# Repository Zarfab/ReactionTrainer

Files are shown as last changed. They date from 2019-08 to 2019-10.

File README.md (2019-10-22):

# ReactionTrainer
These modules are developed with the aim of creating exercises to improve athletes' reflexes.

## How to use

## Make your own

### Bill of material
(For each module)

|Part|Reference|cost|Other information|
|----|----|----|----|
|Micro-controller|ESP32 D1 Mini|3,80€|
|Distance sensor|VL6180X|2.40€|[datasheet](https://www.st.com/resource/en/datasheet/vl6180x.pdf)
|RGB LED ring|WS2812B ring|3.30€|12 LED, outer diameter 52mm|
|Buzzer|12085 16R|0.20€|Often sold in packs of 5 or 10|
|Battery|18650|3.00€|
|Battery holder|For 1x 18650 cell|0.55€|
|On / Off switch|TS-13|1.00€|
|Case|3D printed||

Total cost for a single module is around 15€ without the case.

### Software requirement
- [Arduino IDE 1.8.6](https://www.arduino.cc/en/main/software) or newer with [Arduino Core for ESP32 installed](https://github.com/espressif/arduino-esp32/blob/master/docs/arduino-ide/boards_manager.md)
- [FastLED](https://github.com/FastLED/FastLED) (install latest from Arduino IDE Librairies Manager)
- [arduinoWebSockets](https://github.com/Links2004/arduinoWebSockets) (install latest - at least v 2.x.x - from Arduino IDE Librairies Manager)
- [arduinoJson](https://github.com/bblanchon/ArduinoJson) (install latest - at least v 6.x.x - from Arduino IDE Librairies Manager)
- [VL6180X (Polulu)](https://github.com/pololu/vl6180x-arduino) (install latest from Arduino IDE Librairies Manager)

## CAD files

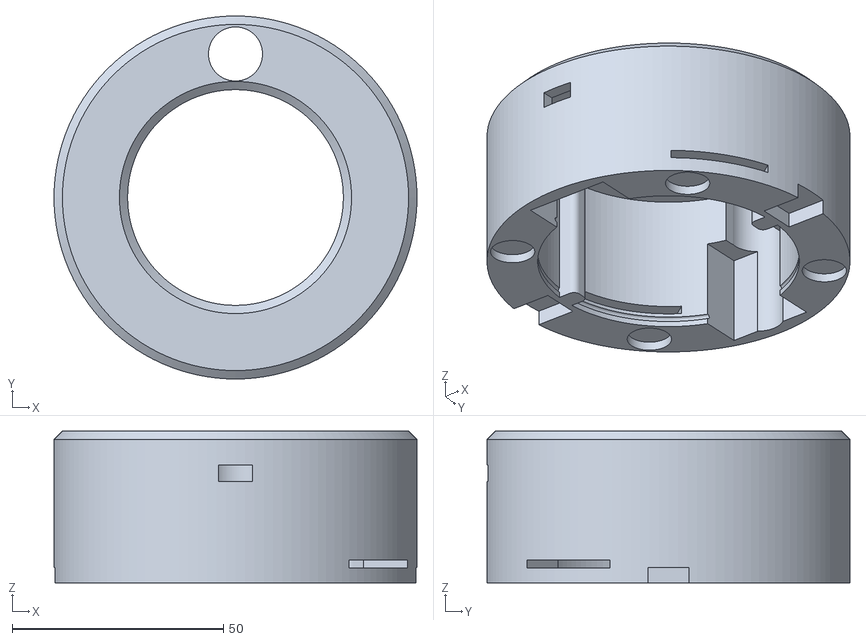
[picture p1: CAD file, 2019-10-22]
CAD/RoundBox.stl
86.0 x 86.0 x 36.0

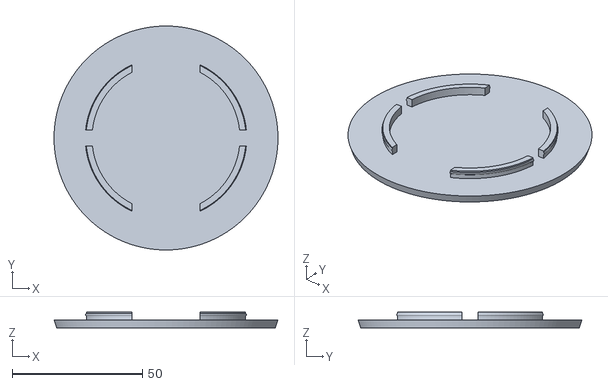
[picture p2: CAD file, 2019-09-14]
CAD/BottomPlate.stl
86.0 x 86.0 x 6.00

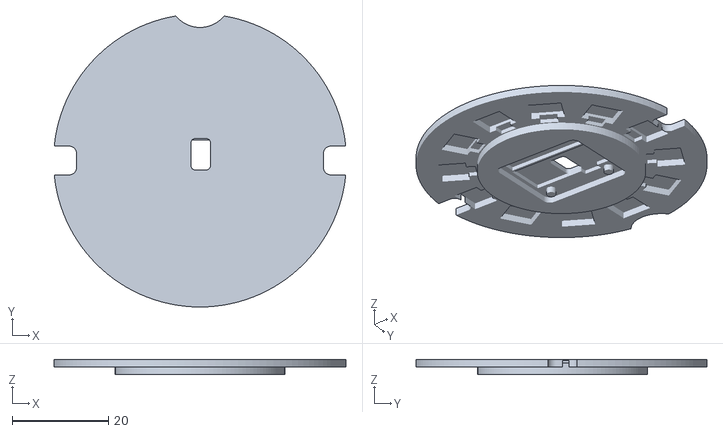
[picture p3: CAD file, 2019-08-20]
CAD/TopPlate.stl
60.5 x 60.4 x 3.20

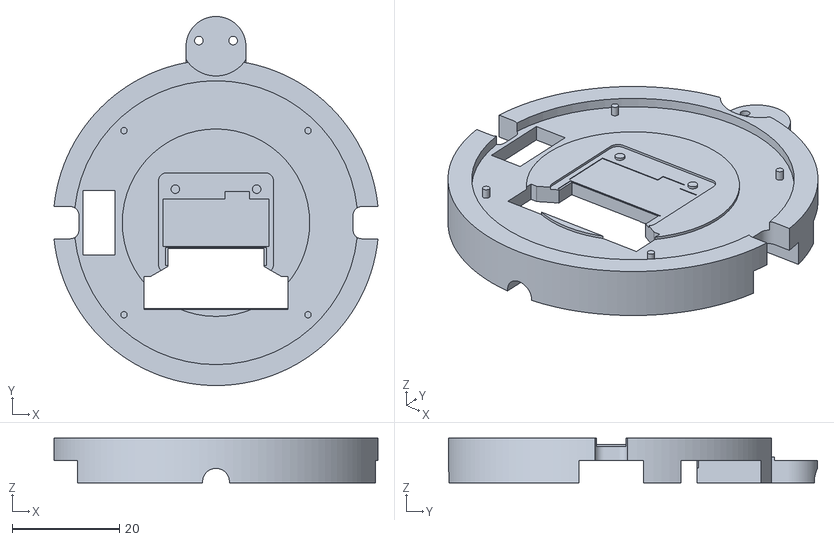
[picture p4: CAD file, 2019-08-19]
CAD/InnerPlate.stl
60.5 x 68.9 x 8.35

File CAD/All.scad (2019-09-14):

use<components.scad>
use<RoundBox.scad>
use<TopPlate.scad>
use<InnerPlate.scad>
use<BottomPlate.scad>


difference() {
    union() {
        roundBox();
        //translate([0, 0, 30.4]) components();
        //#color([0.2, 1, 0.4]) translate([0, 0, 0.6]) batteryHolder();
        //#translate([0, 0, 32.4]) TopPlate();
        //color([0.9, 0.9, 0.9]) translate([0, 0, 27.8]) InnerPlate();
        translate([0, 0, -3]) BottomPlate();
    }
    rotate(60) translate([0, -50, -5]) cube([100, 100, 60]);
}

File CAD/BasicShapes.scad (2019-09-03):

module roundedRect(size, radius)
{
    x = size[0]-radius;
    y = size[1]-radius;
    z = size[2];

    linear_extrude(height=z)
    hull()
    {
        // place 4 circles in the corners, with the given radius
        translate([(-x/2)+(radius/2), (-y/2)+(radius/2), 0])
        circle(r=radius);

        translate([(x/2)-(radius/2), (-y/2)+(radius/2), 0])
        circle(r=radius);

        translate([(-x/2)+(radius/2), (y/2)-(radius/2), 0])
        circle(r=radius);

        translate([(x/2)-(radius/2), (y/2)-(radius/2), 0])
        circle(r=radius);
    }
}



module tore(mainRadius, circleRadius, fn1 = $fn, fn2 = $fn)
{
    rotate_extrude(convexity = 10, $fn = fn1)
    translate([mainRadius, 0, 0])
    circle(r = circleRadius, $fn = fn2);
}

tore(10, 2, fn1 = 120, fn2 = 12);

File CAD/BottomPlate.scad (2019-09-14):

use <BasicShapes.scad>

$fn = 120;

module BottomPlate() {
    difference() {
        union() {
            cylinder(d1=84, d2=86, h=3);
            //translate([0,0,2.9]) cylinder(d=86, h=3.1);
            translate([0,0,3]) difference() {
                union() {
                    space = 0.28;
                    cylinder(d=62 - 2 * space, h=3);
                    translate([0,0,2]) tore(mainRadius=31 - space - 0.2, circleRadius=0.5);
                }
                cylinder(d=56.8, h=3.1);
                translate([31-1.8, 0, 0]) roundedRect(size=[7.2, 6, 4.4], radius=1.6);
        translate([-31+1.8, 0, 0]) roundedRect(size=[7.2, 6, 4.4], radius=1.6);
                translate([0, 0, 3]) cube([26, 78, 6], center=true);
            }
        }
        //translate([0,0,2.9]) cylinder(d=84, h=3.2);
        /*for(i=[0:3]) {
            rotate([0, 0, 45 + i*90]) translate([0, 37, 0.1]) {
                translate([0, 0, -0.2]) cylinder(d=8.2, h=0.3);
                cylinder(d1=8.2, d2=4.4, h=2.4);
                cylinder(d=4.4, h=4.2);
            }
        }*/
    }
}

BottomPlate();

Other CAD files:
CAD/components.scad
CAD/InnerPlate.scad
CAD/RoundBox.scad
CAD/RoundedRect.scad
CAD/TopPlate.scad

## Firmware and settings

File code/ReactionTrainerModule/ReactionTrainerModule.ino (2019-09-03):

#include <WiFi.h>
#include <WebSocketsClient.h>
#include <ArduinoJson.h>
#include "RTModule.h"

#define AP_SSID_PREFIX "REACTION_TRAINER_"
#define AP_PASSWORD "PainIsComing"

#define BOOT_COLOR          CRGB::Gray
#define WIFI_NOT_FOUND      CRGB::Orange
#define WIFI_CONNECTING     CRGB::Yellow
#define WIFI_NOT_CONNECTED  CRGB::Red
#define WIFI_CONNECTED      CRGB::Chartreuse
#define WS_CONNECTED        CRGB::Cyan
#define WS_DISCONNECTED     CRGB::Magenta

#define JSON_OVER_SERIAL false // used at true for debug


DynamicJsonDocument doc(1024);
WebSocketsClient webSocket;
RTModule reactionTrainer;

    
/**************************************************************************/
/*  Arduino main funtions                                                 */
/**************************************************************************/
void setup()
{
  Serial.begin(115200);

  reactionTrainer.init();

  ///// SCAN WIFI NETWORKS /////
  // Set WiFi to station mode and disconnect from an AP if it was previously connected
  if(!JSON_OVER_SERIAL) {
    WiFi.mode(WIFI_STA);
    WiFi.disconnect();
    fill_solid(reactionTrainer.leds, NB_LED, BOOT_COLOR);
    FastLED.show();
    delay(100);
    int n = WiFi.scanNetworks();
    Serial.println("scan done");
    if (n == 0) 
    {
        Serial.println("no network found");
        fill_solid(reactionTrainer.leds, NB_LED, WIFI_NOT_FOUND);
        FastLED.show();
        delay(5000);
        ESP.restart();
    } 
    
    String ssid = "";
    for (int i = 0; i < n; ++i) 
    {
      String currentSsid = WiFi.SSID(i);
      if(currentSsid.indexOf(AP_SSID_PREFIX) == 0) 
      {
        ssid = currentSsid;
        Serial.printf("Will try to connect to %s, signal force is %i dB\n", WiFi.SSID(i), WiFi.RSSI(i));
        fill_solid(reactionTrainer.leds, NB_LED, WIFI_CONNECTING);
        FastLED.show();
        break;
      }
      delay(10);
    }
    if(ssid == "") {
      Serial.printf("no network with %s as prefix\n", AP_SSID_PREFIX);
      fill_solid(reactionTrainer.leds, NB_LED, WIFI_NOT_FOUND);
      FastLED.show();
      delay(5000);
      ESP.restart();
    }
    
    WiFi.begin(ssid.c_str(), AP_PASSWORD);
    int nbTries = 0;
    while(WiFi.status() != WL_CONNECTED) {
      delay(500);
      Serial.print(".");
      if(nbTries % 4 == 3) {
        WiFi.begin(ssid.c_str(), AP_PASSWORD);
      }
      if(nbTries >= 20) {
        Serial.println("impossible to connect to " + ssid + ", check if password is set correctly");
        fill_solid(reactionTrainer.leds, NB_LED, WIFI_NOT_CONNECTED);
        FastLED.show();
        delay(5000);
        ESP.restart();
      }
      nbTries++;
    }
  
    Serial.println();
    Serial.println("WiFi connected");
    Serial.print("SSID: ");
    Serial.println(WiFi.SSID());
    Serial.print("IP address: ");
    Serial.println(WiFi.localIP());
    fill_solid(reactionTrainer.leds, NB_LED, WIFI_CONNECTED);
    FastLED.show();
    delay(100);
  
    webSocket.begin("192.168.4.1", 8025, "/rt");
    webSocket.onEvent(webSocketEvent);
    webSocket.setReconnectInterval(5000);
  }
  else {
    fill_solid(reactionTrainer.leds, NB_LED, BOOT_COLOR);
    FastLED.show();
    delay(100);
  }
}



void loop()
{
  if(!JSON_OVER_SERIAL) webSocket.loop();
  else {
    if(Serial.available()) {
      DeserializationError err = deserializeJson(doc, Serial);
      if(err == DeserializationError::Ok)
        reactionTrainer.handleJson(doc.as<JsonObject>());
      else 
        Serial.printf("deserializeJson() failed with code %s\n", err.c_str());
    }
  }
  String answer = reactionTrainer.update();
  if(answer != "")
  {
    if(!JSON_OVER_SERIAL) webSocket.sendTXT(answer);
    else Serial.println(answer);
  }
  FastLED.show();
}



/**************************************************************************/
/*  WebSocket callbacks                                                   */
/**************************************************************************/
void webSocketEvent(WStype_t type, uint8_t * payload, size_t length)
{
    switch(type)
    {
        case WStype_DISCONNECTED:
          Serial.printf("[WSc] Disconnected!\n");
          fill_solid(reactionTrainer.leds, NB_LED, WS_DISCONNECTED);
          break;
        case WStype_CONNECTED:
          Serial.printf("[WSc] Connected to url: %s\n", payload);
          fill_solid(reactionTrainer.leds, NB_LED, WS_CONNECTED);
          break;
        case WStype_TEXT:
        {
          Serial.printf("[WSc] get text: %s\n", payload);
          DeserializationError err = deserializeJson(doc, payload);
          if(err == DeserializationError::Ok)
            reactionTrainer.handleJson(doc.as<JsonObject>());
          else 
            Serial.printf("deserializeJson() failed with code %s\n", err.c_str());
        }
        break;
      default:  
        break;
    }
}

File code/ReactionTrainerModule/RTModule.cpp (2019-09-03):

#include "RTModule.h"

RTModule::RTModule() :
  brightness(32), groupColor(0xff0000), presentSelf(false), shotT0(-1), buzzerOn(false)
{
  defaultShot.distanceThreshold = 200;
  defaultShot.timeout = 4000;
  defaultShot.order = SIMULTANEOUS;
  
  defaultShot.colorDuration = 1500;
  fill_solid(defaultShot.colorPalette, 16, CRGB::Blue);
  defaultShot.colorAnim = COLOR_ANIM_NONE;
  
  defaultShot.soundDuration = 0;
  defaultShot.soundFreq = -1;
}



void RTModule::init()
{
  ///// SETUP FASTLED AND DISPLAY BATTERY LEVEL /////
  FastLED.addLeds<WS2812B, LED_PIN, GRB>(leds, NB_LED).setCorrection( TypicalLEDStrip );
  FastLED.setBrightness(brightness);
  showBatteryLevel();
  FastLED.delay(1000);
  // setup VL6180X sensor
  Wire.begin();
  sensor.init();
  sensor.configureDefault();
  sensor.setTimeout(200);
  // setup buzzer
  ledcSetup(buzzerChannel, 440, 8);
  ledcAttachPin(BUZZER_PIN, buzzerChannel);
}



String RTModule::update()
{
  String str = "";
  if(presentSelf) {
    StaticJsonDocument<64> doc;
    doc["type"] = "RTModule";
    doc["version"] = RT_VERSION;
    char buf[64];
    serializeJson(doc, buf);
    str += buf;
    presentSelf = false;
    return str;
  }
  if(shotT0 >= 0) {
    int64_t reactTime = millis() - shotT0;
    // play sound
    if(!buzzerOn && shot.soundFreq > 20 && reactTime >= shot.soundT0) {
      ledcWriteTone(buzzerChannel, shot.soundFreq);
      buzzerOn = true;
    }
    // stop sound;
    if(buzzerOn && reactTime >= shot.soundTEnd) {
      ledcWriteTone(buzzerChannel, 0);
      buzzerOn = false;
      shot.soundFreq = -1; // prevent from playing again
    }
    // play color animation
    if(reactTime >= shot.colorT0 && reactTime < shot.colorTEnd) {
      int64_t animTime = reactTime - shot.colorT0;
      float animProgress = animTime / (float)(shot.colorDuration);
      int paletteIndex = round(255.0 * animProgress);
      CRGB currentColor = ColorFromPalette(shot.colorPalette, paletteIndex);
      switch(shot.colorAnim) {
        case COLOR_ANIM_NONE:
          fill_solid(leds, NB_LED, shot.colorPalette[0]);
          break;
        case COLOR_ANIM_STILL:
          fill_solid(leds, NB_LED, currentColor);
          break;
        case COLOR_ANIM_BLINK:
        {
          bool isBlack = animTime % 200 >= 100;
          fill_solid(leds, NB_LED, isBlack? CRGB::Black : currentColor);
        }
          break;
        case COLOR_ANIM_TIMER:
        {
          for(int i = 0; i < NB_LED; i++) {
            if(i <= floor(animProgress * NB_LED)) {
              leds[i] = currentColor;
            }
            else {
              leds[i] = CRGB::Black;
            }
          }
        }
          break;
        case COLOR_ANIM_STOPWATCH:
        {
          for(int i = 0; i < NB_LED; i++) {
            if(i <= floor((1.0 - animProgress) * NB_LED)) {
              leds[i] = currentColor;
            }
            else {
              leds[i] = CRGB::Black;
            }
          }
        }
          break;
        case COLOR_ANIM_LOADING:
        {
          fill_solid(leds, NB_LED, CRGB::Black);
          int firstLed = (NB_LED * animTime / 492) % NB_LED;
          for(int i = firstLed; i < firstLed + NB_LED / 2; i++) {
            leds[i % NB_LED] = currentColor;
          }
        }
          break;
        case COLOR_ANIM_WHEEL:
        {
          fill_solid(leds, NB_LED, CRGB::Black);
          int firstLed = (NB_LED * animTime / 2000) % 4;
          for(int i = firstLed; i < NB_LED; i += 4) {
              leds[i] = currentColor;
          }
          break;
        }
        default:
          break;
      }
    }
    else {
      fill_solid(leds, NB_LED, CRGB::Black);
    }
    
    // read sensor value
    uint16_t val = sensor.readRangeSingle();
    if (val <= shot.distanceThreshold || reactTime > shot.timeout) {
      StaticJsonDocument<64> doc;
      doc["result"] = val <= shot.distanceThreshold? 1 : 0;
      doc["reactionTime"] = reactTime;
      char buf[64];
      serializeJson(doc, buf);
      str += buf;
      shotT0 = -1;
      fill_solid(leds, NB_LED, CRGB::Black);
      ledcWriteTone(buzzerChannel, 0);
      buzzerOn = false; 
    }
  }
  return str;
}



void RTModule::handleJson(const JsonObject& doc)
{
  JsonVariant brightnessJson = doc["brightness"];
  JsonVariant groupColorJson = doc["groupColor"];
  if(!brightnessJson.isNull() && !groupColorJson.isNull()) {
    brightness = brightnessJson.as<uint8_t>();
    groupColor = groupColorJson.as<int>();
    presentSelf = strcmp(doc["answerExpected"], "true") == 0;
    FastLED.setBrightness(brightness);
    fill_solid(leds, NB_LED, groupColor);
    FastLED.show();
    FastLED.delay(1000);
    fill_solid(leds, NB_LED, CRGB::Black);
    FastLED.show();
  }
  else
  {
    // configure and measure reaction time
    shot.distanceThreshold = doc["distanceThreshold"] | defaultShot.distanceThreshold;
    shot.timeout = doc["timeout"] | defaultShot.timeout;
    shot.order = doc["order"].as<uint8_t>() | defaultShot.order;
  
    shot.colorDuration = doc["colorDuration"] | defaultShot.colorDuration;
    shot.colorAnim = doc["colorAnim"].as<uint8_t>() | defaultShot.colorAnim;
    JsonArray palette = doc["colorPalette"];
    if(palette.isNull())
    {
      CRGB colorBeg = doc["colorBegin"].as<int>();
      if(colorBeg) {
        CRGB colorEnd = doc["colorEnd"].as<int>();
        if(colorEnd) {
          fill_gradient_RGB(shot.colorPalette, 16, colorBeg, colorEnd);
        }
        else {
          fill_solid(shot.colorPalette, 16, colorBeg);
        }
      }
      else {
        shot.colorPalette =  defaultShot.colorPalette;
      }
    }
    else
    {
      fill_solid(shot.colorPalette, 16, CRGB::Black);
      int i = 0;
      for(JsonVariant v : palette) 
      {
        shot.colorPalette[i] = v.as<int>();
        i++;
        if(i == 16) break;
      }
    }
  
    shot.soundDuration = doc["soundDuration"] | defaultShot.soundDuration;
    shot.soundFreq = doc["soundFreq"] | defaultShot.soundFreq;

    switch(shot.order) {
      case COLOR_BEFORE:
        shot.colorT0 = 0;
        shot.colorTEnd = shot.colorDuration;
        shot.soundT0 = shot.colorDuration;
        shot.soundTEnd = shot.colorDuration + shot.soundDuration;
        break;
      case SOUND_BEFORE:
        shot.colorT0 = shot.soundDuration;
        shot.colorTEnd = shot.soundDuration + shot.colorDuration;
        shot.soundT0 = 0;
        shot.soundTEnd = shot.soundDuration;
        break;
      default:
        shot.colorT0 = 0;
        shot.colorTEnd = shot.colorDuration;
        shot.soundT0 = 0;
        shot.soundTEnd = shot.soundDuration;
        break;
    }
    shotT0 = millis();
  }
}
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

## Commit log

2019-08-18 First draw of CAD finished
    [BottomPlate.scad, BottomPlate.stl, InnerPlate.scad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]
2019-08-18 Correct led ring size
2019-08-18 adjust components size and tolerance
    [InnerPlate.scad, InnerPlate.stl, TopPlate.scad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]
2019-08-18 adjust innerplate
    [InnerPlate.stl]
2019-08-19 adjust tolerances for easy box mounting
    [BottomPlate.scad, BottomPlate.stl, InnerPlate.scad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]
2019-08-20 redesign bottom closing and adjust tolerances on top plate
    [BottomPlate.scad, BottomPlate.stl, RoundBox.scad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]
2019-08-20 create readme for printing parameters
    [RoundBox.stl]
2019-08-21 add sketch to test if soldering is good
    [ReactionTrainer_wiring.fzz]
2019-08-29 add timer and stopwatch animations - to be tested
2019-08-29 Loading and wheel animations to be fixed
2019-09-03 update 3d models
    [All.scad, BasicShapes.scad, BottomPlate.scad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]
2019-09-14 last fix on bottom plate clip
    [All.scad, BottomPlate.scad, BottomPlate.stl]
2019-10-22 add space for magnets
    [RoundBox.scad, RoundBox.stl]
2019-10-22 add space for velcro strap
    [RoundBox.scad, RoundBox.stl]
